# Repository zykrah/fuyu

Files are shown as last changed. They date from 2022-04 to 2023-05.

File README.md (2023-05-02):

# Fuyu
 F12 TKL H87-Compat Type-C PCB for the Geon F1-8K, designed in KiCAD 6.0.
 
 > Fuyu, meaning Winter (in Japanese ofcourse)

## Availability

**UPDATE: I have partenered with Geon to make these available for purchase! As of writing, they are available [here on Geon's store](https://geon.works/products/fuyu-pcb-for-f1-8k).**

**They are also [available on CustomKBD](https://customkbd.com/products/fuyu-pcb-for-f1-8k).**





## Photos/Renders 
I try to keep them up to date, but they may not always be:







IRL photos of rev1 protos (See further down the page for more photos):







## Features
- Fits the h87(c) standard (means it should also be compatible with the F1-8X (non-f13))
- Uses the RP2040 MCU (new), with 16MB of external flash
- Has the 5 extra keys required for the F1-8X numpad/blocker (See below)
- Has programmable 7 SK6812 Mini-E ARGB LEDs for the "snowflake" (See below)
- Has 34 underglow LEDs (WS2812(C)-2020 LEDs)
- Multi-layout (see below)
- BOOT pins/header for getting into bootloader (short the pins while plugging in) if [bootmagic](https://github.com/qmk/qmk_firmware/blob/master/docs/feature_bootmagic.md) isn't available . Acessible from both sides of the PCB, even when PCB is built in a keyboard. Just remove the **END key/switch** to access it.
- SWD header for debugging
- ESD chip (SRV05-4) to prevent damage from electrostatic discharge
- Polyfuse to prevent overcurrent
- Optimized for manufacturing and assembly with JLCPCB
- Bonus: Curved traces and teardrops

> Also, `Sleep-Lib` is just the library by [Sleepdealer](https://github.com/Sleepdealr), used in his [RP2040 Design guide](https://github.com/Sleepdealr/RP2040-designguide).

## Firmware
~~As of writing, the board runs the rp2040 branch/fork of vial-qmk. I will update this to use the official QMK implementation of RP2040 when it releases.~~

~~UPDATE: RP2040 support has recently made it into QMK's `develop` branch. It will be fully merged to `master` by Q3 this year. Until then, the official maintainer of vial doesn't intend to merge those changes into their vial repo either, so I have made my own fork for the boards. When vial-qmk is officially updated to use QMK's implementiation of the RP2040, I will update this page once again linking to that, assuming I get the board merged into the official repo too.~~

~~UPDATE 2: RP2040 support has now been merged to `master`. I have not yet submitted PRs to merge the FUYU into the official qmk/vial-qmk yet. For now, you can find the up-to-date firmware [here](https://github.com/zykrah/vial-qmk/tree/vdev-zykrah/keyboards/zykrah/fuyu).~~

You can find the up-to-date VIAL firmware [here](https://github.com/zykrah/vial-qmk/tree/vial-stable-zykrah/keyboards/zykrah/fuyu). This firmware utilises [VIAL](https://get.vial.today/download/). Download and run it, and it should automatically detect the board. (Boards sold on Geon's store should come with VIAL firmware installed by default)

**UPDATE**: The board is now also in [qmk master](https://github.com/qmk/qmk_firmware/tree/master/keyboards/zykrah/fuyu). (This particular version will only be VIA compatible). It should automatically be detected in VIA if you want to use that instead.



### Flashing

To flash an RP2040 board, you need to get it into bootloader mode. You can do this in two ways:
1. If the board already has functioning QMK firmware on it, you can simply hold the top left key (ESC) while plugging the board in
2. If for some reason the first method doesn't work, you can enter bootloader by shorting the `BOOT` pins located underneath the END key while plugging the board in

The board will appear as a drive on your computer as `RPI-RP2`.



Then you just need to move/copy/drag the firmware file (`.uf2` file) into that drive, and it should flash.

## WIP/Ideas
- ~~Add underglow LEDs~~ DONE
- Add more underglow LEDs to make the lighting more consistent
- Add removable USB port + JST/Daughterboard connector
- ~~Add ISO support (enter and pipe keys)~~ DONE
- Add more split space support/bottom row layout options
- Add layout indicators to the silkscreen of the pcb
- Do something more special with USB shield/ground connection (currently shield is connected straight to ground)
- Break out pins for 3v3, 5v, spare GPIO
- More via stitching

## Multi-Layout Support



## Snowflake LED

The LEDs are typically TX LEDs that you have to solder in (i.e. Snow Pro PCB), but with this PCB I made them SK6812 Mini-E Reverse-mount ARGB LEDs

- Reverse mount to keep as many components on the same side of the PCB as possible (for cheaper assembly)
- RGB and programmable
- NOTE: Since these are surface mounted onto the PCB, they'll probably leak light. Could be fixed with light pipes or something else used to isolate the led rays from eachother. 

Snowflake LED IRL (NOTE: brightness has been modified in firmware to lower light leak):



What it looks like close up on my PCB (KICAD preview/renders):





## Blocker

Blocker attached, unattached, and outside the board (test fit photos courtesy of my friend):







 What blocker looks like screwed in from the back:



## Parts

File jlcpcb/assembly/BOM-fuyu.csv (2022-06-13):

Comment | Designator | Footprint | LCSC
1k | R4,R5 | R_0402_1005Metric | C11702
100nF | C10,C11,C12,C17,C18,C19,C2,C20,C21,C22,C23,C24,C25,C26,C27,C28,C29,C3,C30,C31,C32,C33,C34,C35,C36,C37,C38,C39,C40,C41,C42,C43,C44,C45,C46,C47,C48,C49,C50,C51,C52,C53,C54,C55,C56,C57,C58,C6,C7,C8,C9 | C_0402_1005Metric | C1525
10uF | C4 | C_0402_1005Metric | C15525
22pF | C15,C16 | C_0402_1005Metric | C1555
RP2040 | U2 | RP2040-QFN-56 | C2040
27R | R2,R3 | R_0603_1608Metric | C25190
10k | R1 | R_0402_1005Metric | C25744
5.1k | R6,R7 | R_0402_1005Metric | C25905
1uF | C1,C13,C14,C5 | C_0402_1005Metric | C52923
XC6206 | U1 | SOT-23 | C5446
500mA | F1 | Fuse_1206_3216Metric | C70076
74AHCT1G125 | U5 | SOT-23-5 | C7484
D | D1,D10,D11,D12,D13,D14,D15,D16,D17,D18,D19,D2,D20,D21,D22,D23,D24,D25,D26,D27,D28,D29,D3,D30,D31,D32,D33,D34,D35,D36,D37,D38,D39,D4,D40,D41,D42,D43,D44,D45,D46,D47,D48,D49,D5,D50,D51,D52,D53,D54,D55,D56,D57,D58,D59,D6,D60,D61,D62,D63,D64,D65,D66,D67,D68,D69,D7,D70,D71,D72,D73,D74,D75,D76,D77,D78,D79,D8,D80,D81,D82,D83,D84,D85,D86,D87,D88,D89,D9,D90,D91,D92,D93,D94,D95 | D_SOD-123 | C81598
SRV05-4 | U3 | SOT-23-6-routable | C85364
12MHz | Y1 | Crystal_SMD_3225-4Pin_3.2x2.5mm | C9002
WS2812_2020 | D100,D101,D102,D103,D104,D105,D106,D107,D108,D109,D110,D111,D112,D113,D114,D115,D116,D117,D118,D119,D120,D121,D122,D123,D124,D125,D126,D127,D128,D129,D130,D131,D132,D133 | LED_WS2812_2020 | C965556
W25Q128JVS | U4 | SOIC-8_5.23x5.23mm_P1.27mm | C97521
SK6812MINI-E | LED3 | LED_6028R
? | SW97 | SW_MX_1u
? | SW66 | SW_MX_1u
? | SW104 | SW_MX_1.5u
? | SW87 | SW_MX_1u
? | SW28 | SW_MX_1u
? | SW41 | SW_MX_1u
? | SW2 | SW_MX_1u
? | SW10 | SW_MX_1u
? | SW27 | SW_MX_1u
? | SW34 | SW_MX_1u
? | SW35 | SW_MX_1u
? | SW11 | SW_MX_1u
? | SW58 | SW_MX_1u
? | SW73 | SW_MX_1u
? | SW8 | SW_MX_1u
? | SW68 | SW_MX_1u
? | SW88 | SW_MX_1u
? | SW47 | SW_MX_1u
? | SW39 | SW_MX_1u
? | SW16 | SW_MX_1u
? | SW6 | SW_MX_1u
? | SW25 | SW_MX_1u
? | SW29 | SW_MX_1u
? | SW99 | SW_MX_1.25u
? | SW13 | SW_MX_1u
? | SW63 | SW_MX_1u
ANSI_ENTER | S3 | STAB_MX_2.25u
? | SW101 | SW_MX_1.25u
SK6812MINI-E | LED4 | LED_6028R
? | SW23 | SW_MX_1u
? | SW89 | SW_MX_1u
? | SW94 | SW_MX_1u
? | SW76 | SW_MX_1u
? | SW51 | SW_MX_1u
? | SW59 | SW_MX_1u
? | SW36 | SW_MX_1.5u
? | SW60 | SW_MX_1u
? | SW72 | SW_MX_1.25u
6.25U_SPACE | S6 | STAB_MX_6.25u
? | SW33 | SW_MX_1u
? | SW30 | SW_MX_1u
? | SW42 | SW_MX_1u
? | SW4 | SW_MX_1u
? | SW69 | SW_MX_1u
? | SW98 | SW_MX_1u
? | SW74 | SW_MX_1u
? | SW82 | SW_MX_1u
? | SW100 | SW_MX_1.5u
? | SW48 | SW_MX_1u
? | SW91 | SW_MX_1.25u
? | SW56 | SW_MX_1u
? | SW75 | SW_MX_1u
? | SW31 | SW_MX_1u
? | SW80 | SW_MX_1u
? | SW54 | SW_MX_1.75u_stp
? | SW64 | SW_MX_1u
? | SW21 | SW_MX_1u
BACKSPACE | S1 | STAB_MX_2u
? | SW3 | SW_MX_1u
? | SW84 | SW_MX_1u
SK6812MINI-E | LED5 | LED_6028R
? | SW44 | SW_MX_1u
? | SW78 | SW_MX_1u
? | SW15 | SW_MX_1u
? | SW106 | SW_MX_1u
SK6812MINI-E | LED7 | LED_6028R
? | SW57 | SW_MX_1u
? | SW79 | SW_MX_1u
? | SW46 | SW_MX_1u
? | SW24 | SW_MX_1u
? | SW43 | SW_MX_1u
? | SW12 | SW_MX_1u
? | SW77 | SW_MX_1u
? | SW83 | SW_MX_1u
? | SW61 | SW_MX_1u
? | SW50 | SW_MX_1u
? | SW45 | SW_MX_1u
? | SW22 | SW_MX_1u
? | SW103 | SW_MX_1.25u
? | SW53 | SW_MX_1u
? | SW37 | SW_MX_1u
? | SW20 | SW_MX_1u
? | SW14 | SW_MX_1u
SK6812MINI-E | LED1 | LED_6028R
? | SW81 | SW_MX_1u
RSHIFT | S5 | STAB_MX_2.75u
? | SW7 | SW_MX_1u
? | SW70 | SW_MX_1u
? | SW18 | SW_MX_1u
? | SW5 | SW_MX_1u
? | SW49 | SW_MX_1.5u
? | SW1 | SW_MX_1u
? | SW62 | SW_MX_1u
? | SW9 | SW_MX_1u
? | SW67 | SW_MX_1u
USB_C | J1 | USB_C_Receptacle_HRO_TYPE-C-31-M-12
? | SW71 | SW_MX_1u
? | SW32 | SW_MX_1u
? | SW95 | SW_MX_1.25u
? | SW105 | SW_MX_1.25u
? | SW65 | SW_MX_1u
? | SW90 | SW_MX_1u
? | SW55 | SW_MX_1.75u
ISO_ENTER | S2 | STAB_MX_ISO_FLIPPED
? | SW85 | SW_MX_1.75u
? | SW38 | SW_MX_1u
? | SW92 | SW_MX_1.5u
? | SW19 | SW_MX_1u
? | SW17 | SW_MX_1u
? | SW93 | SW_MX_1.25u
? | SW102 | SW_MX_1u
? | SW96 | SW_MX_1.5u
SK6812MINI-E | LED2 | LED_6028R
? | SW52 | SW_MX_1u
? | SW26 | SW_MX_1u
? | SW40 | SW_MX_1u
SK6812MINI-E | LED6 | LED_6028R
? | SW86 | SW_MX_1u
LSHIFT | S4 | STAB_MX_2.25u
7U_SPACE | S7 | STAB_MX_7u
? | SW108 | SW_MX_1u
? | SW107 | SW_MX_1u

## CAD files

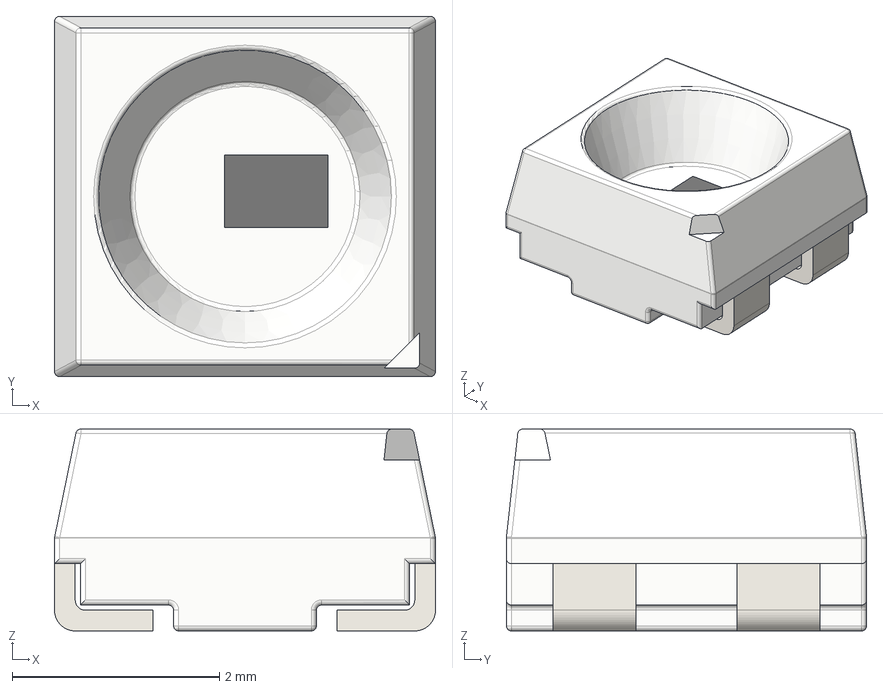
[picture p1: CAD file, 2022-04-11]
marbastlib/3d/LED_WS2812B-MINI.step
3.68 x 3.48 x 1.95 mm

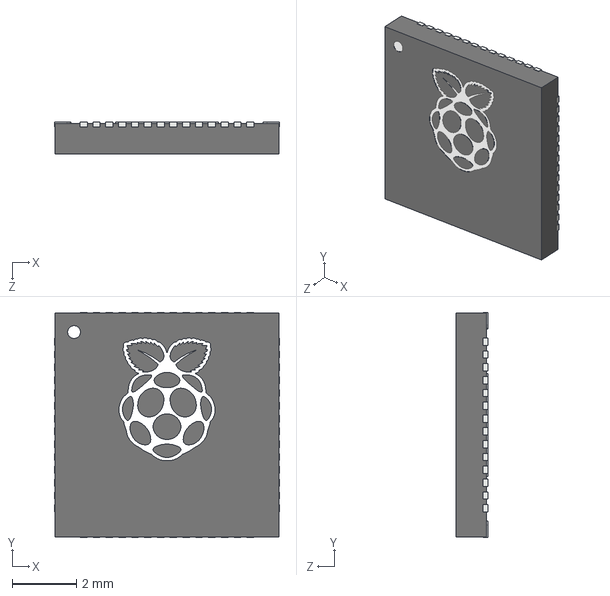
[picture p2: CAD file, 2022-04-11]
Sleep-lib/RP2040_QFN_PACKAGE.STEP
7.02 x 7.02 x 1.00 mm

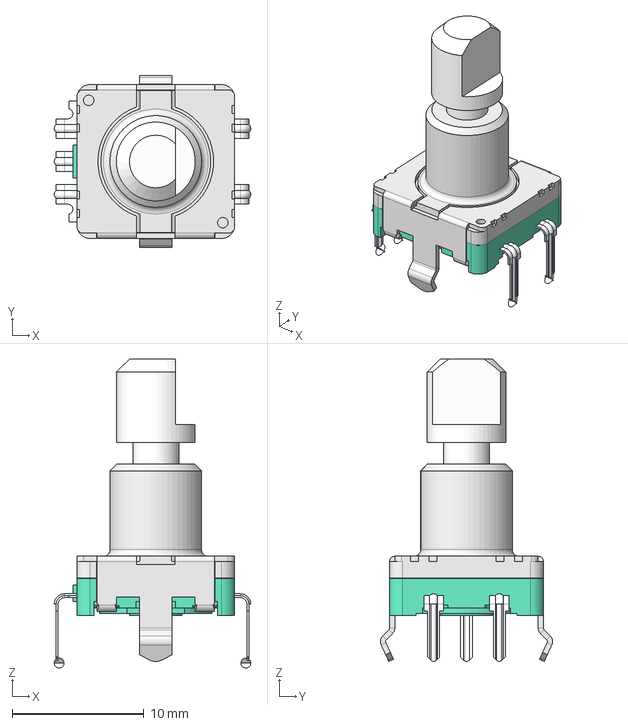
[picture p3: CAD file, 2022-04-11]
marbastlib/3d/ROT_EC11N.step
14.9 x 13.1 x 23.5 mm

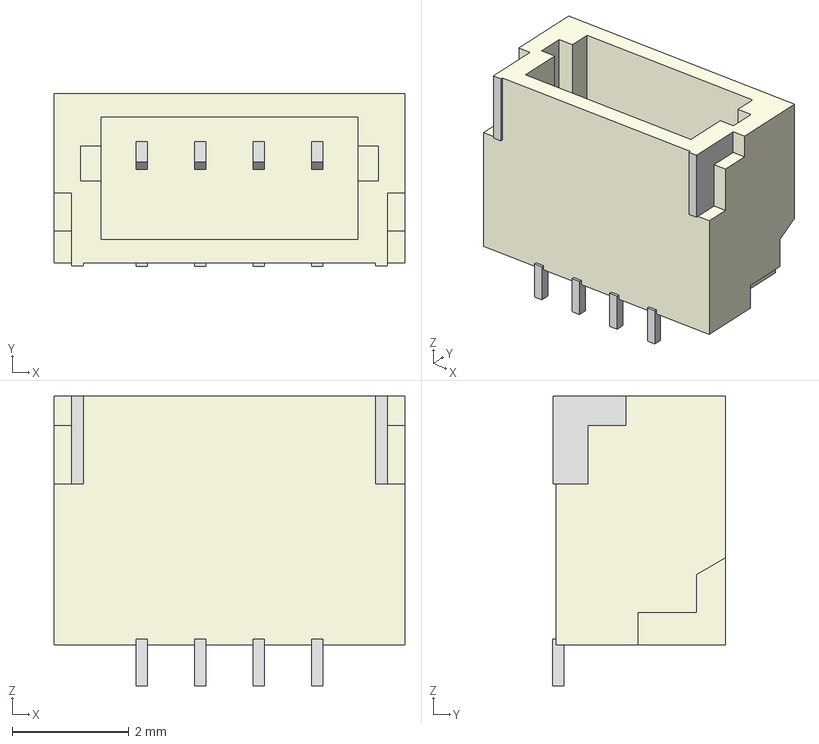
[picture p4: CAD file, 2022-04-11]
marbastlib/3d/CON_SM04B-SRSS-TB.step
6.00 x 2.96 x 4.95 mm

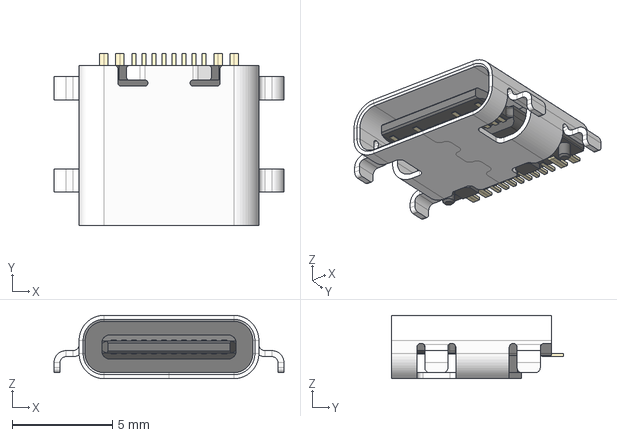
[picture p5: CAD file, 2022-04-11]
marbastlib/3d/CON_TYPE-C-31-M-14.step
11.5 x 8.56 x 3.16 mm
Shroud
Plastic Body & Connector

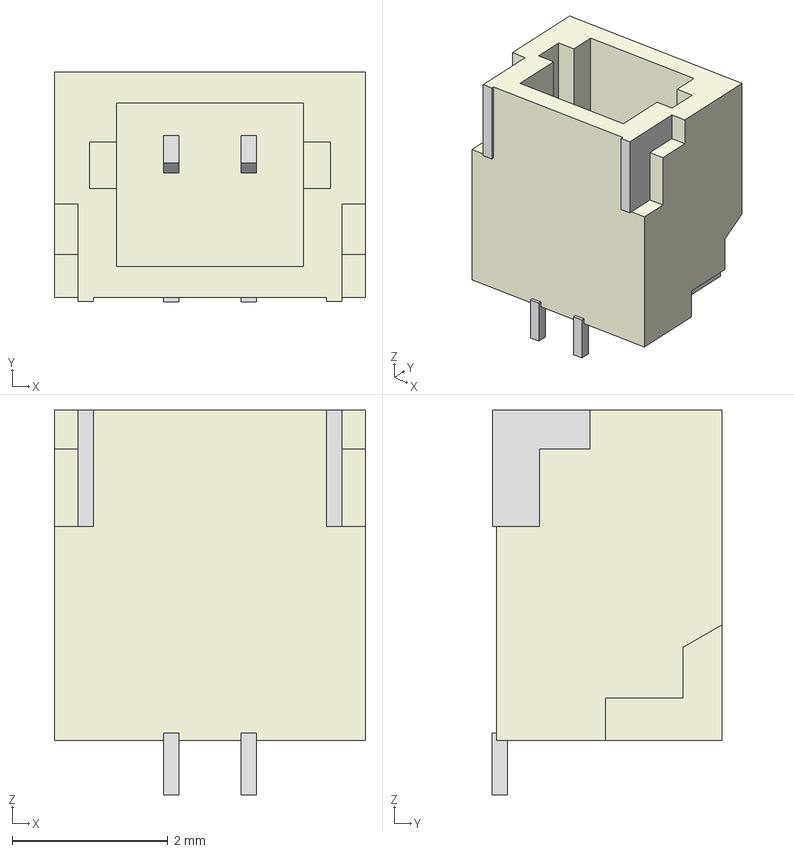
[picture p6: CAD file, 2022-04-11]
marbastlib/3d/CON_SM02B-SRSS-TB.step
4.00 x 2.96 x 4.95 mm

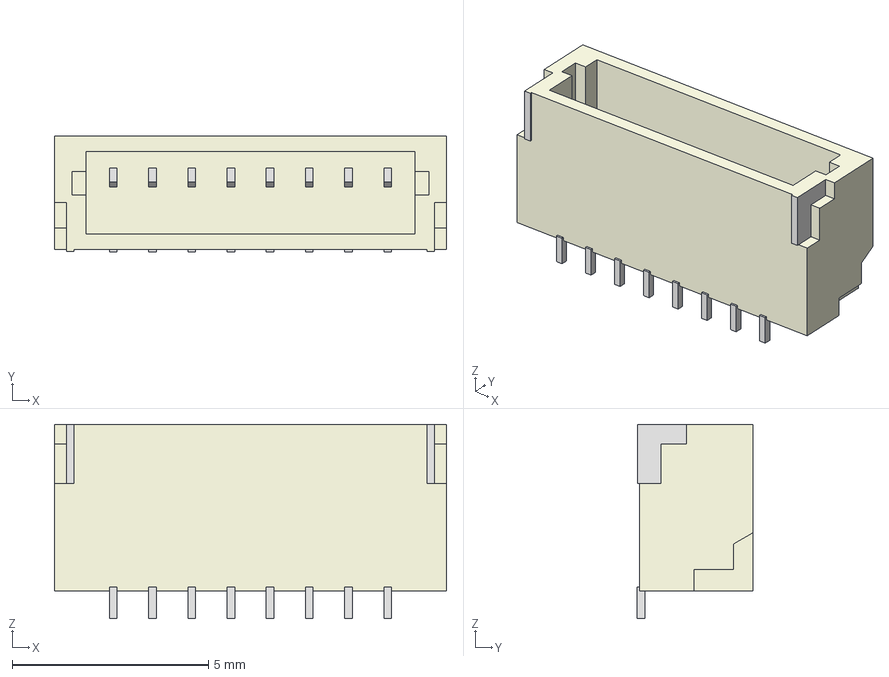
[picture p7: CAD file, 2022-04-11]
marbastlib/3d/CON_SM08B-SRSS-TB.step
10.0 x 2.96 x 4.95 mm

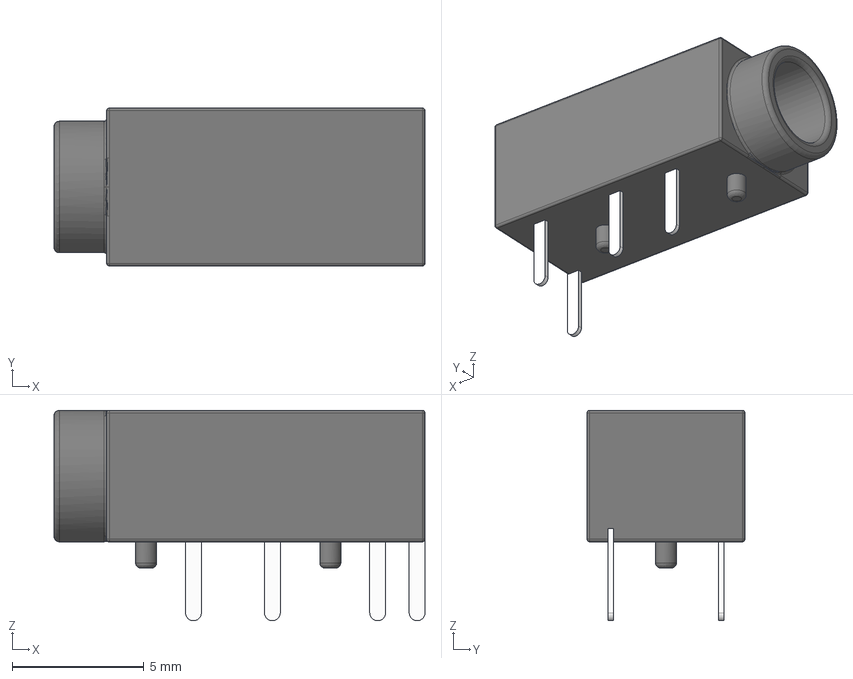
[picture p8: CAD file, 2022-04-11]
marbastlib/3d/CON_MJ-4PP-9.step
14.1 x 6.00 x 8.00 mm

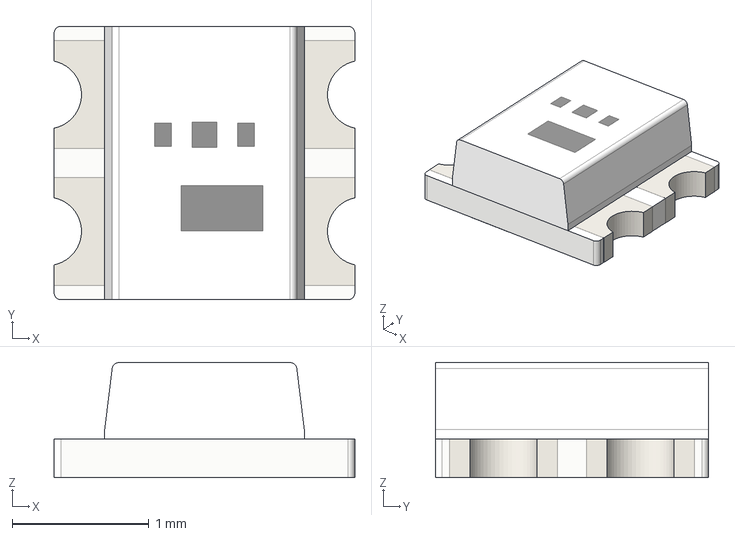
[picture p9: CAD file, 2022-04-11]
marbastlib/3d/LED_WS2812_2020.step
2.20 x 2.00 x 0.842 mm

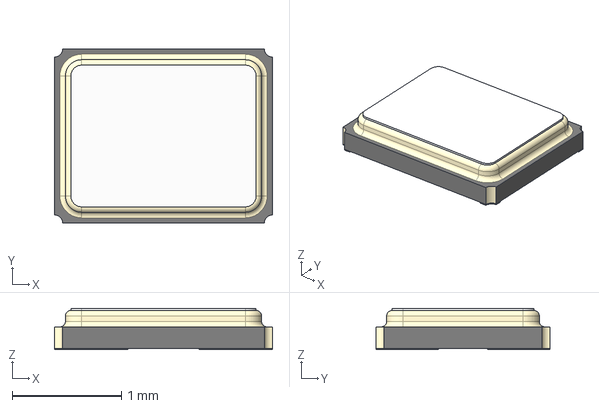
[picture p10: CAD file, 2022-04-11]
marbastlib/3d/Crystal_FA-128.step
2.00 x 1.60 x 0.38 mm

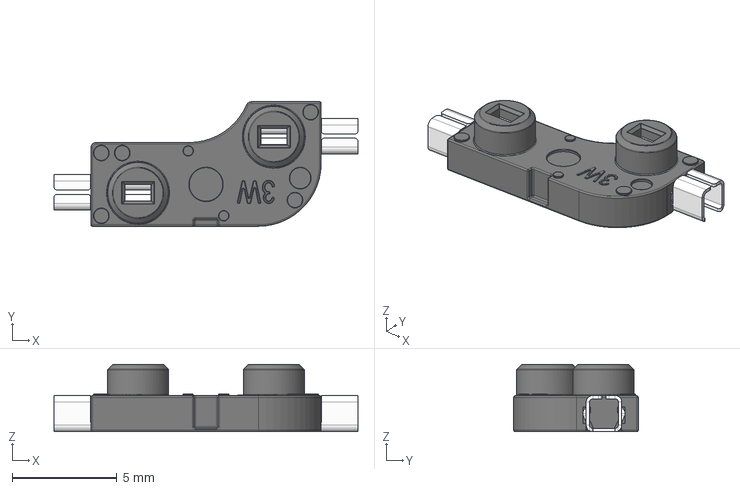
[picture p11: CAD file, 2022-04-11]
marbastlib/3d/HS_Kailh_MX.step
14.5 x 5.95 x 3.22 mm

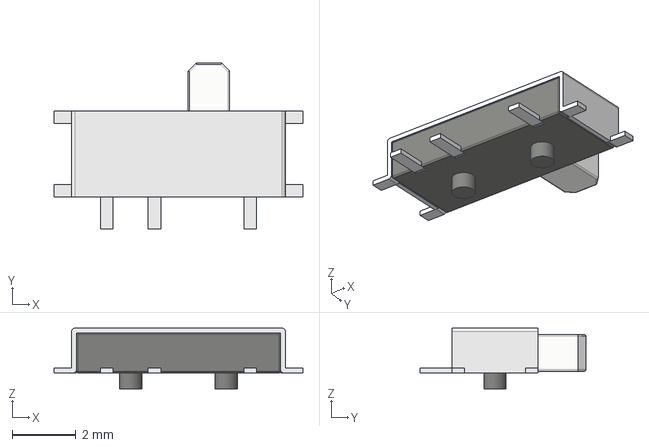
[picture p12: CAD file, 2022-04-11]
marbastlib/3d/MSK12C02.step
7.80 x 5.20 x 1.90 mm

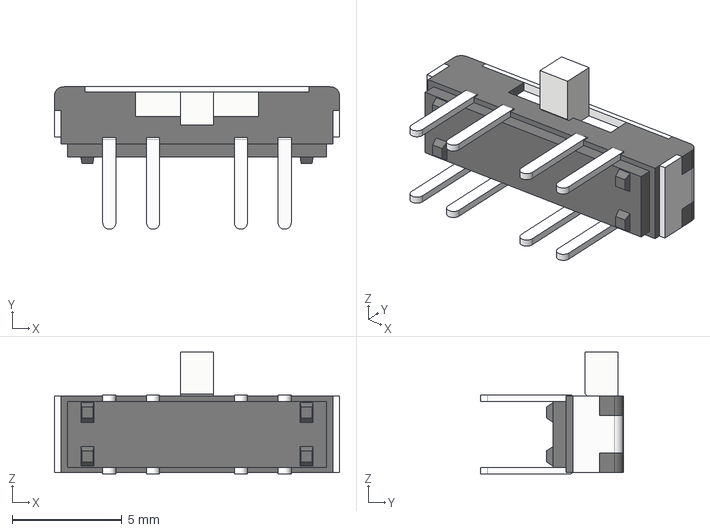
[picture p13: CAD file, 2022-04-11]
marbastlib/3d/SW_SSSS223900.step
13.0 x 6.50 x 5.55 mm

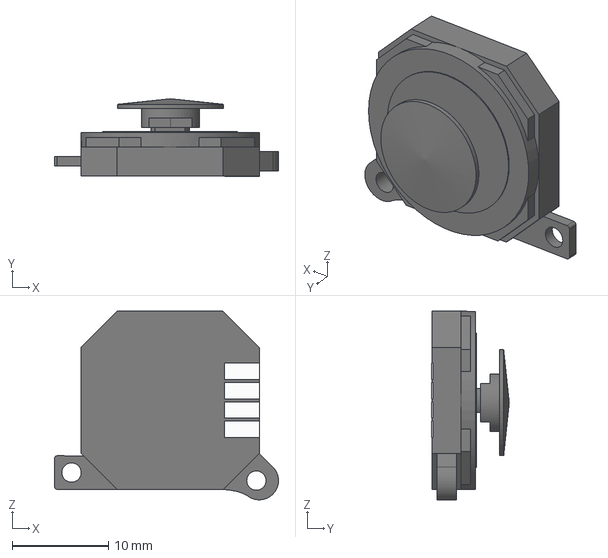
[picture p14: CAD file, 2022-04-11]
marbastlib/3d/joystick_psp1000.step
23.2 x 8.05 x 19.6 mm

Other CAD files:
marbastlib/3d/holyiot_18010_nRF52840.step
marbastlib/3d/CON_SM06B-SRSS-TB.step
marbastlib/3d/Switch_ESP3020.step
marbastlib/3d/CON_SM05B-SRSS-TB.step
marbastlib/3d/CON_SM07B-SRSS-TB.step
marbastlib/3d/CON_SM13B-SRSS-TB.step
marbastlib/3d/CON_TYPE-C-31-M-12.step
marbastlib/3d/HS_Kailh_Choc.step
marbastlib/3d/LED_SK6812MINI-E.step
marbastlib/3d/ROT_EC11E.step
marbastlib/3d/SW_SKHLLC.step
marbastlib/3d/SW_SSSS213100.step
marbastlib/3d/Switch_MSK12C02.step
marbastlib/3d/Switch_SKQG.step

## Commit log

2022-04-11 (Actual) Initial commit
    Inital commit was from my other hotswap f13 h88 board.
    This commit changes:
    - hotswap footprints into solder footprints
    - added more switches above arrow keys
    - completely re-traced the matrix
    - updated some orientations of symbols and footprints
    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
    [fuyu.kicad_sch, matrix.kicad_sch]
2022-04-11 Further revision... Added LEDs
    - Added snowflake "badge" leds
    - Added LED indicators
    - fixed up many major tiny issues
    - changed all vias to minimum 0.3/0.6mm to meet jlcpcb spec
    [fuyu.kicad_sch, matrix.kicad_sch]
2022-06-11 Changed to SKMINI-E LEDs, silkscreen
    -Added text + graphics to silkscreen
    -Changed the snowflake leds from THT leds to skmini-e leds
    -Some routing cleanup
    [fuyu.kicad_sch, matrix.kicad_sch]
2022-06-11 [WIP] Added Underglow LEDs
    -Changed internal routing of 1v1 and 3v3 under MCU
    -Updated SWD silkscreen
    -Using WS2812C-2020 LEDs for underglow
    -More small routing changes
    [fuyu.kicad_sch, matrix.kicad_sch]
2022-06-11 Minor Cleanup, changes to BOM files
    -Added 470 ohm resistor to argb line
    [fuyu.kicad_sch, matrix.kicad_sch]
2022-06-11 Minor silkscreen fix/update
    Diodes, capacitors, etc
2022-06-11 Updated main PCB renders/images
2022-06-11 Added missing GND vias around snowflake
2022-06-11 Add 470 ohm data resistor to schematic
    I forgot to save before :skull:
    [fuyu.kicad_sch, matrix.kicad_sch]
2022-06-11 ISO Support Added, Major rerouting
    For some reason some people still use ISO... This was a pain to route (had to move entire MCU and re-route a lot. (No longer as clean :cry:)
    [fuyu.kicad_sch, matrix.kicad_sch]
2022-06-11 Minor filleting
    Forgot some traces
2022-06-12 Put ESD before Fuse
    As per recommendations by multiple people
    [fuyu.kicad_sch]
2022-06-12 Removed LED indicators, Fix + Update to Underglow
    -Completely removed LED indicators (reasoning: resistor values were too easy to get wrong, snowflake exists instead)
    -Moved traces + rotated leds to make underglow nicer
    -Added more GND vias
    -More minor updates to routing + bug squashing
    [fuyu.kicad_sch, matrix.kicad_sch]
2022-06-13 Lots of changes, underglow + snowflake
    -Added a 74AHCT1G125 level shifter on the ARGB data line (+100nF cap)
    -Removed 470 ohm resistor on data line
    -"Forked" out the 5V instead of looping around the board
    -Changes to routing of underglow
    -Added 100nF caps for the SK mini-E leds (snowflake)
    -Changes to snowflake routing
    -Lots of GND vias added for via stitching
    -Minor changes to silkscreens
    -Minor routing changes
    -Gave more room around screw holes for ISO stabs to prevent shorts
    -Updated BOM slightly
    [fuyu.kicad_sch, matrix.kicad_sch]
2022-06-13 Added gerbers, bom and pos files
    -Removed jlcpcb from gitignore
    [BOM-fuyu.csv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]
2022-06-13 Changed level shifter to SOT-23
    -Because of cost savings/part shortages
    -Rerouted around level shifter
    -Moved around flash, rerouted that area
    -Updated JLC BOM
    -Updated LCSC numbers in schematic
    [BOM-fuyu.csv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]
